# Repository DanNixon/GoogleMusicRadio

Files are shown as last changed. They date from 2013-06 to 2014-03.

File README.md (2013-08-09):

GoogleMusicRadio
================
Internet radio which streams music form a Google Play library using a Raspberry Pi and Arduino.

Overview
--------
Allows browsing and playing tracks from a Google Play music library on a hardware internet radio, browsing library is done through a Artist>Album>Track menu structure (or a Playlist>Track structure in the case of playlists).

The radio is intended to be used with [Last.fm](http://last.fm) to report the currently playing track, scrobble listened tracks and to love tracks at the request of the user.

A basic user interface of 6 buttons, two rotary encoders with push in switches and a 4 row, 20 column LCD is used, although it is possible to use various sizes of LCD based on specific user requirements enclosure designs.

Note that this radio is designed to work with a personal library only, personally I don't use the All Access service so have no need to support it, but feel free to add this functionality, the Google Music API does support All Access radio.

Requirements
------------
Libraries required for Arduino and Raspberry Pi are listed in the respective folders.

Build Instructions
------------------
A complete guide to building a radio is available [here](http://www.instructables.com/id/Google-Play-Music-Internet-Radio-Raspberry-Pi-and/) on Instructbles.

A demo of the final project is available [here](http://www.youtube.com/watch?v=tgPbvo-8iRc).

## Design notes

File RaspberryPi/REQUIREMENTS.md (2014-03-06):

Requirements
============

The following libraries need to be installed on the Pi:
-	[Google Music API](https://github.com/simon-weber/Unofficial-Google-Music-API) (currently requires ```develop``` branch)
-	[GStreamer](http://gstreamer.freedesktop.org/) (core and Python bindings)
-	[pyLast](http://code.google.com/p/pylast/)
-	[pySerial](http://pyserial.sourceforge.net/)

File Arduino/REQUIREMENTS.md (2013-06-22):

Requirements
============

The following Arduino libraries are needed:
-	LiquidCrystal (in default libraries)
-	[Encoder](http://www.pjrc.com/teensy/td_libs_Encoder.html)
-	[CmdMessenger](http://playground.arduino.cc/Code/CmdMessenger)
-	[Streaming](http://arduiniana.org/libraries/streaming/) (needed by CmdMessenger)

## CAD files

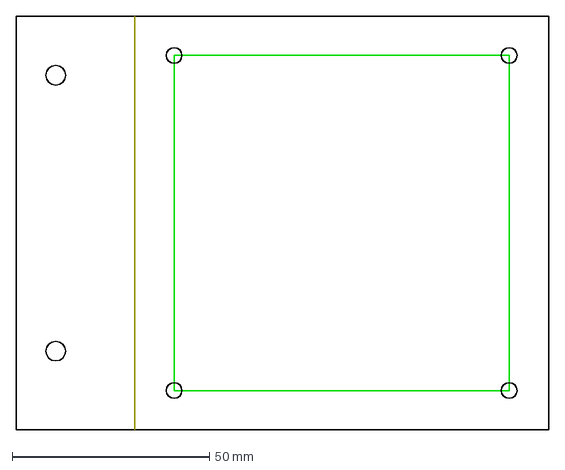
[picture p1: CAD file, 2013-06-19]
LibreCAD/MainBoardMount.dxf
135.0 x 105.0 mm

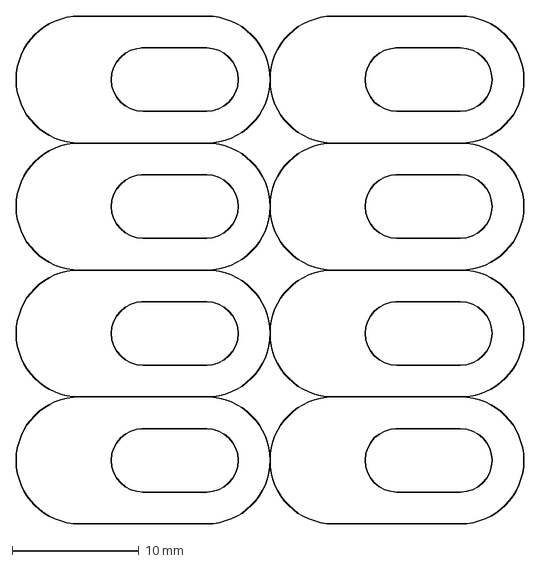
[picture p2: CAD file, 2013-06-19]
LibreCAD/LCD_Retainer.dxf
40.0 x 40.0 mm

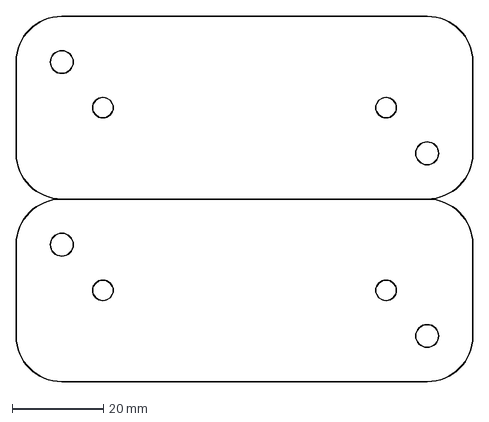
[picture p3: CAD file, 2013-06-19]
LibreCAD/AmplifierMounts.dxf
100.0 x 80.0 mm

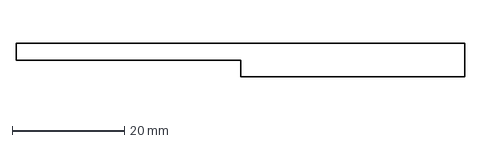
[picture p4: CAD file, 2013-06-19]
LibreCAD/LCD_Spacer.dxf
80.0 x 6.00 mm

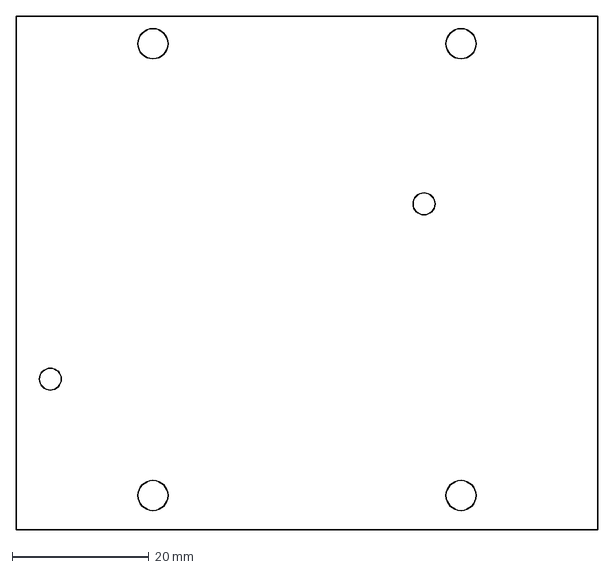
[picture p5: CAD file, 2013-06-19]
LibreCAD/RaspPiMount_GPR.dxf
85.0 x 75.0 mm

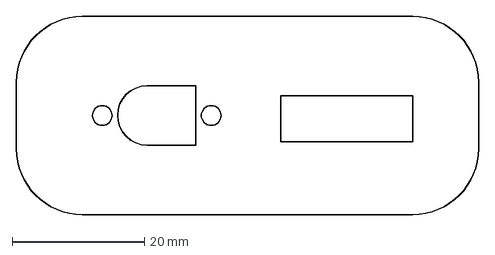
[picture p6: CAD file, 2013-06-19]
LibreCAD/GPR_RearPower.dxf
70.0 x 30.0 mm

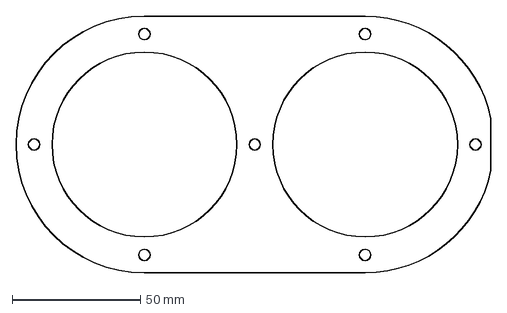
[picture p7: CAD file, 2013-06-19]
LibreCAD/DualSpeakerMount.dxf
185.0 x 100.0 mm

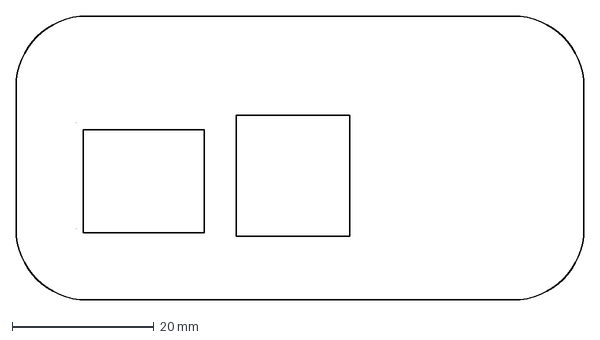
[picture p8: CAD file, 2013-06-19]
LibreCAD/RearRaspPiCover.dxf
80.0 x 40.0 mm

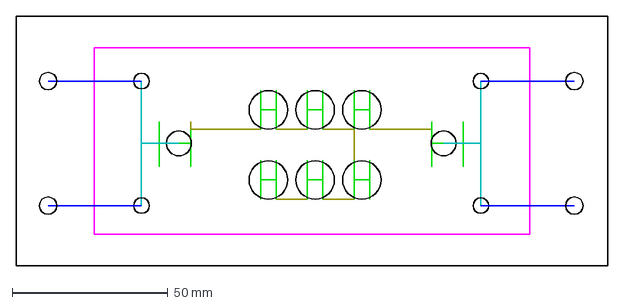
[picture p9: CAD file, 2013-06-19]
LibreCAD/GPR_FrontPanel_A.dxf
190.0 x 80.0 mm

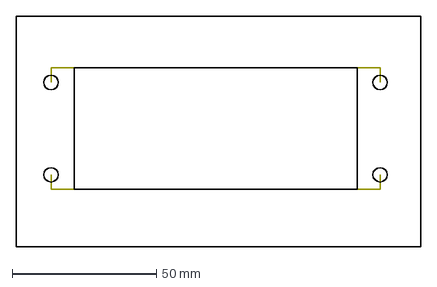
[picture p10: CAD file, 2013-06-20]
LibreCAD/LCD_Screw_Template.dxf
140.0 x 80.0 mm

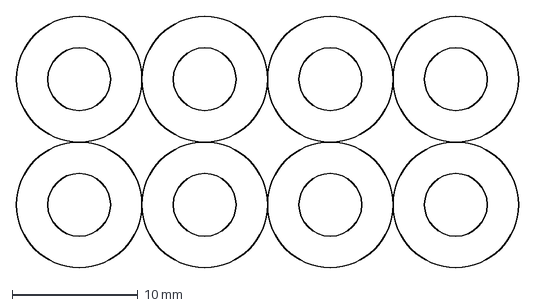
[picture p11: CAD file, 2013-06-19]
LibreCAD/Washers.dxf
40.0 x 20.0 mm

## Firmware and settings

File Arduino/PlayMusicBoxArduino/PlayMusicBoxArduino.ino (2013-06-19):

/*
  Google Pay Music Radio Arduino script
  Dan Nixon 2013
  dan-nixon.com
  
  11/04/2013
*/

#include <Encoder.h>
#include <LiquidCrystal.h>
#include <CmdMessenger.h>
#include <Streaming.h>

#define PORT_SPEED 115200

char field_separator = '%';
char command_separator = '~';

const int ADC_TH = 100;
const int DB_TIME = 20;

const int LCD_ROWS = 4;
const int LCD_COLS = 20;

//LCD PINS
#define LCD_D4 11
#define LCD_D5 10
#define LCD_D6 9
#define LCD_D7 8
#define LCD_RS 13
#define LCD_EN 12

//ENCODERS
#define VOL_ENC_A 3
#define VOL_ENC_B 5
#define CUR_ENC_A 2
#define CUR_ENC_B 4
long volEncPos = -999;
long curEncPos = -999;
static const int VOL_ENCODER_DELTA = 1;
static const int CUR_ENCODER_DELTA = 1;

//ENCODER BUTTONS
#define SELECT_PIN 6
boolean selLast = false;
#define MUTE_PIN 7
boolean muteLast = false;

//ADC BUTTONS
#define STOP_ADC 0
boolean stopLast = false;
#define PLAY_ADC 1
boolean playLast = false;
#define NEXT_ADC 2
boolean nextLast = false;
#define LOVE_ADC 4
boolean loveLast = false;
#define DISP_ADC 3
boolean dispLast = false;
#define BACK_ADC 5
boolean backLast = false;

Encoder volumeEnc(VOL_ENC_A, VOL_ENC_B);
Encoder cursorEnc(CUR_ENC_A, CUR_ENC_B);
CmdMessenger msgr = CmdMessenger(Serial, field_separator, command_separator);
LiquidCrystal lcd(LCD_RS, LCD_EN, LCD_D4, LCD_D5, LCD_D6, LCD_D7);

//COMMAND LIST
enum
{
  kCOMM_ERROR    = 000,
  kACK           = 001,
  kARDUINO_READY = 002,
  kERR           = 003,
  kNEXT          = 012, //10
  kSTOP          = 013,
  kPLAY          = 014,
  kBACK          = 015,
  kINCVOL        = 016,
  kDECVOL        = 017,
  kUP            = 020,
  kDOWN          = 021,
  kSEL           = 022,
  kDISP          = 023,
  kLOVE          = 024, //20
  kMUTE          = 025,
  kSEND_CMDS_END,
};

messengerCallbackFunction messengerCallbacks[] = 
{
  lcdPrint,
  lcdVolume,
  lcdClear,
  NULL
};

//CALLBACKS
void lcdPrint() {
  msgr.sendCmd(kACK, "LCD_P");
  int rowNo = msgr.readInt();
  char row[LCD_COLS + 1] = {};
  msgr.copyString(row, (LCD_COLS + 1));
  lcd.setCursor(0, rowNo);
  lcd.print(row);
}

void lcdClear() {
  msgr.sendCmd(kACK, "LCD_C");
  lcd.clear();
}

void lcdVolume() {
  msgr.sendCmd(kACK, "VOL_P");
  int volume = msgr.readInt();
  float barRange = LCD_COLS - 2;
  float barWeight = 64.0 / barRange;
  int barQuant = (int) (volume / barWeight);
  lcd.clear();
  lcd.setCursor(0,0);
  lcd.print("Volume: ");
  lcd.setCursor(8, 0);
  lcd.print(volume);
  lcd.setCursor(0, 1);
  lcd.print("[");
  lcd.setCursor((LCD_COLS - 1), 1);
  lcd.print("]");
  lcd.setCursor(1, 1);
  for(int i = 0; i < barQuant; i++) {
    lcd.write(255);
  }
}

//DEFAULT CALLBACKS
void arduino_ready() {
  msgr.sendCmd(kACK,"READY");
}

void unknownCmd() {
  msgr.sendCmd(kERR,"U_CMD");
}

//SETUP

void attach_callbacks(messengerCallbackFunction* callbacks) {
  int i = 0;
  int offset = kSEND_CMDS_END;
  while(callbacks[i]) {
    msgr.attach(offset+i, callbacks[i]);
    i++;
  }
}

void setup() {
  Serial.begin(PORT_SPEED);
  msgr.print_LF_CR();
  msgr.attach(kARDUINO_READY, arduino_ready);
  msgr.attach(unknownCmd);
  attach_callbacks(messengerCallbacks);
  lcd.begin(LCD_COLS, LCD_ROWS);
  //PIN CONFS
  pinMode(SELECT_PIN, INPUT);
  digitalWrite(SELECT_PIN, HIGH);
  pinMode(MUTE_PIN, INPUT);
  digitalWrite(MUTE_PIN, HIGH);
  long volEncPos = volumeEnc.read();
  long curEncPos = cursorEnc.read();
  arduino_ready();
  lcd.print("Waiting for Pi...");
}

//MAIN LOOP
void checkButtons() {
  if(analogRead(PLAY_ADC) <= ADC_TH) {
    if(playLast == false) {
      msgr.sendCmd(kPLAY, "PLAY");
      delay(DB_TIME);
      playLast = true;
    }
  } else {
    if(playLast == true) {
      playLast = false;
    }
  }
  
  if(analogRead(STOP_ADC) <= ADC_TH) {
    if(stopLast == false) {
      msgr.sendCmd(kSTOP, "STOP");
      delay(DB_TIME);
      stopLast = true;
    }
  } else {
    if(stopLast == true) {
      stopLast = false;
    }
  }
  
  if(analogRead(NEXT_ADC) <= ADC_TH) {
    if(nextLast == false) {
      msgr.sendCmd(kNEXT, "NEXT");
      delay(DB_TIME);
      nextLast = true;
    }
  } else {
    if(nextLast == true) {
      nextLast = false;
    }
  }
  
  if(analogRead(BACK_ADC) <= ADC_TH) {
    if(backLast == false) {
      msgr.sendCmd(kBACK, "BACK");
      delay(DB_TIME);
      backLast = true;
    }
  } else {
    if(backLast == true) {
      backLast = false;
    }
  }
  
  if(analogRead(DISP_ADC) <= ADC_TH) {
    if(dispLast == false) {
      msgr.sendCmd(kDISP, "DISP");
      delay(DB_TIME);
      dispLast = true;
    }
  } else {
    if(dispLast == true) {
      dispLast = false;
    }
  }
  
  if(analogRead(LOVE_ADC) <= ADC_TH) {
    if(loveLast == false) {
      msgr.sendCmd(kLOVE, "LOVE");
      delay(DB_TIME);
      loveLast = true;
    }
  } else {
    if(loveLast == true) {
      loveLast = false;
    }
  }
  if(digitalRead(SELECT_PIN) == LOW) {
    if(selLast == false) {
      msgr.sendCmd(kSEL, "SEL");
      delay(DB_TIME);
      selLast = true;
    }
  } else {
    if(selLast == true) {
      selLast = false;
    }
  }
  if(digitalRead(MUTE_PIN) == LOW) {
    if(muteLast == false) {
      msgr.sendCmd(kMUTE, "MUTE");
      delay(DB_TIME);
      selLast = true;
    }
  } else {
    if(muteLast == true) {
      muteLast = false;
    }
  }
}

void checkEncoders() {
  long newVolEncPos = volumeEnc.read();
  if(newVolEncPos > (volEncPos + VOL_ENCODER_DELTA)) {
    msgr.sendCmd(kDECVOL, "DECVOL");
    volEncPos += VOL_ENCODER_DELTA;
  }
  else if(newVolEncPos < (volEncPos - VOL_ENCODER_DELTA)) {
    msgr.sendCmd(kINCVOL, "INCVOL");
    volEncPos -= VOL_ENCODER_DELTA;
  }
  
  long newCurEncPos = cursorEnc.read();
  if(newCurEncPos > (curEncPos + CUR_ENCODER_DELTA)) {
    msgr.sendCmd(kUP, "UP");
    curEncPos += CUR_ENCODER_DELTA;
  }
  else if(newCurEncPos < (curEncPos - CUR_ENCODER_DELTA)) {
    msgr.sendCmd(kDOWN, "DOWN");
    curEncPos -= CUR_ENCODER_DELTA;
  }
}

void loop() 
{
  msgr.feedinSerialData();
  checkButtons();
  checkEncoders();
}

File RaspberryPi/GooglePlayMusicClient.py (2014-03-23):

#!/usr/bin/python

## Google Play Music client script for Rasp. Pi radio
## Copyright: Dan Nixon 2012-13
## dan-nixon.com
## Version: 0.4
## Date: 04/03/2014

import thread, time, random, string
from gmusicapi import Mobileclient
import RPi.GPIO as gpio
import smbus
import serial
import gobject, glib
import gst

#__MusicClient__ = None
#__MediaPlayer__ = None
#__VolumeMan__ = None
#__LCDMan__ = None
#__LastFm__ = None
#__LCDMenuMan__ = None
__SerialPort__ = None

class switch(object):
	def __init__(self, value):
		self.value = value
		self.fall = False

	def __iter__(self):
		yield self.match
		raise StopIteration
    
	def match(self, *args):
		if self.fall or not args:
			return True
		elif self.value in args:
			self.fall = True
			return True
		else:
			return False

class GPMClient(object):
	all_songs_album_title = "All Songs"
	thumbs_up_playlist_name = "Thumbs Up"

	def __init__(self, email, password, device_id):
		self.__api = Mobileclient()
		self.logged_in = False
		self.__device_id = device_id

		attempts = 0
		while not self.logged_in and attempts < 3:
			self.logged_in = self.__api.login(email, password)
			attempts += 1

		self.all_tracks = dict()
		self.playlists = dict()
		self.library = dict()

	def __del__(self):
		self.__api.logout()

	def update_local_lib(self):
		print "Getting all library tracks"
		songs = self.__api.get_all_songs()
		self.playlists[self.thumbs_up_playlist_name] = list()

		#	Get main library
		print "Processing library tracks"
		song_map = dict()	
		for song in songs:
			if "rating" in song and song["rating"] == "5":
				self.playlists[self.thumbs_up_playlist_name].append(song)

			song_id = song["id"]
			song_artist = song["artist"]
			song_album = song["album"]

			song_map[song_id] = song

			if song_artist == "":
				song_artist = "Unknown Artist"

			if song_album == "":
				song_album = "Unknown Album"

			if not (song_artist in self.library):
				self.library[song_artist] = dict()
				self.library[song_artist][self.all_songs_album_title] = list()

			if not (song_album in self.library[song_artist]):
				self.library[song_artist][song_album] = list()

			self.library[song_artist][song_album].append(song)
			self.library[song_artist][self.all_songs_album_title].append(song)

		# Sort albums by track number
		print "Sorting library tracks"
		for artist in self.library.keys():
			for album in self.library[artist].keys():
				if album == self.all_songs_album_title:
					sorted_album = sorted(self.library[artist][album], key=lambda k: k['title'])
				else:
					sorted_album = sorted(self.library[artist][album], key=lambda k: k['trackNumber'])
				self.library[artist][album] = sorted_album

		#	Get all playlists
		print "Getting user playlists"
		plists = self.__api.get_all_user_playlist_contents()
		for plist in plists:
			plist_name = plist["name"]
			self.playlists[plist_name] = list()
			for track in plist["tracks"]:
				song = song_map[track["trackId"]]
				self.playlists[plist_name].append(song)

	def get_stream_url(self, song):
		return self.__api.get_stream_url(song["id"], self.__device_id)

	def rate_song(self, song, rating):
		try:
			song["rating"] = rating
			song_list = [song]
			self.__api.change_song_metadata(song_list)
			print "Gave a Thumbs Up to {0} by {1} on Google Play.".format(song["title"].encode("utf-8"), song["artist"].encode("utf-8"))
		except:
			print "Error giving a Thumbs Up on Google Play."

class MediaPlayer(object):
	def __init__(self):
		self.__player = None
			
		self.now_playing_song = None
		self.queue = list()
		self.queue_index = -1

		self.random = False
		self.repeat = True

		thread.start_new_thread(self.player_thread, ())
	
	def __del__(self):
		self.now_playing_song = None
		self.__player.set_state(gst.STATE_NULL)
	
	def player_thread(self):
		if self.__player == None:
			print "Creating a new GStreamer player..."
			self.__player = gst.element_factory_make("playbin2", "player")
			self.__player.set_state(gst.STATE_NULL)
			bus = self.__player.get_bus()
			bus.add_signal_watch()
			bus.connect("message", self.handle_song_end)
			glib.MainLoop().run()
		else:
			print "Player already exists!"
	
	def get_state(self):
		return self.__player.get_state()[1]

	def handle_song_end(self, bus, message):
		if message.type == gst.MESSAGE_EOS:
			__LastFm__.scrobble(self.now_playing_song)
			self.stop()
			print "Finished playing last song"
			self.play_next_in_queue()
	
	def clear_queue(self):
		self.queue = list()
		self.queue_index = -1
		__LCDMenuMan__.update_queue()

	def play(self, song):
		print "Song: ", song
		song_url = __MusicClient__.get_stream_url(song)
		print "Got song URL: ", song_url
		try:
			print "Playing song."
			if not __VolumeMan__.is_mute:
				__VolumeMan__.set_amp_power(True)
			self.__player.set_property("uri", song_url)
			self.__player.set_state(gst.STATE_PLAYING)
			self.now_playing_song = song
			time.sleep(0.5)
			__LCDMan__.update()
		except AttributeError:
			print "Player does not yet exist!"
		__LastFm__.update_now_playing(song)

	def toggle_playback(self):
		try:
			player_state = self.__player.get_state()[1]
			if player_state == gst.STATE_PAUSED:
				print "Resuming paused playback"
				if not __VolumeMan__.is_mute:
					__VolumeMan__.set_amp_power(True)
				self.__player.set_state(gst.STATE_PLAYING)
				if __LCDMan__.lcd_base == __LCDMan__.base_playing:
					__LCDMan__.update()
			elif player_state == gst.STATE_PLAYING:
				print "Pausing playback"
				self.__player.set_state(gst.STATE_PAUSED)
				if not __VolumeMan__.is_mute:
					__VolumeMan__.set_amp_power(False)	
				if __LCDMan__.lcd_base == __LCDMan__.base_playing:
					__LCDMan__.update()
			elif player_state == gst.STATE_NULL:
				print "Nothing in player"
				self.play_next_in_queue()
				if __LCDMan__.lcd_base == __LCDMan__.base_playing:
					__LCDMan__.update()
		except AttributeError:
			print "Player does not yet exist!"

	def stop(self):
		try:
			print "Stopping playback"
			self.__player.set_state(gst.STATE_NULL)
			self.now_playing_song = None
		except AttributeError:
			print "Player does not yet exist!"

	def play_next_in_queue(self):
		print "Playing next song in queue"
		if self.random:
			self.queue_index = random.randint(0, (len(self.queue) - 1))
		else:
			self.queue_index = self.queue_index + 1
		if self.queue_index == len(self.queue):
			if self.repeat:
				self.queue_index = 0
			else:
				self.stop()
				__VolumeMan__.set_amp_power(False)
				print "The queue is empty!"
				return
		next_song = self.queue[self.queue_index]
		self.play(next_song)

	def add_to_queue(self, song):
		print "Adding song to queue. Song ID: ", song["id"]
		self.queue.append(song)
		__LCDMenuMan__.update_queue()

	def next(self):
		__LastFm__.scrobble(self.now_playing_song)
		self.stop()
		self.play_next_in_queue()
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

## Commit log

2013-06-19 Added KiCAD files
    [MainBoard.sch]
2013-06-20 Finished speaker mount and added LCD mounting screw template
    [LCD_Screw_Template.dxf]
2013-06-24 Updated script for new API, fixed bugs
    [GooglePlayMusicClient.py]
2013-06-25 Fixed bugs and issue #1
    [GooglePlayMusicClient.py]
2013-06-25 Fixed artist letter selection sorting bug
    [GooglePlayMusicClient.py]
2013-06-27 Fixed issue #2 + bug fixes
    [GooglePlayMusicClient.py]
2013-07-16 Added LCD update delay after play song
    Fixed strange behaviour which causes Arduino to loose connectivity to the LCD when changing song.
    [GooglePlayMusicClient.py]
2013-07-16 LCD big fix
    This actually fixes the LCD bug that the last commit was supposed to.
    [GooglePlayMusicClient.py]
2013-07-17 Bug fixes and general improvement
    Fixes unlikely case which causes Arduino to hang/reset.
    Amplifier power is no longer toggled during song switch.
    [GooglePlayMusicClient.py]
2013-07-18 Fixed several things
    Fixed issue #3, more consistent LCD messages, better organised Settings menu (now using list instead of dict)
    [GooglePlayMusicClient.py]
2013-08-31 Fixed LCD bug
    First call to writeLCD would cause unwanted characters on LCD if shorter than "Waiting for Pi..." message.
    [GooglePlayMusicClient.py]
2014-03-04 Switch to mobile client, new client code, major refactoring
2014-03-05 More refactoring and corrections
    [GooglePlayMusicClient.py]
2014-03-05 Error handling and refactoring
    [GooglePlayMusicClient.py]
2014-03-06 Fixed some small issues Removed playlist track sorting (gives user order)
    [GooglePlayMusicClient.py]
2014-03-23 Fixed CPU usage issue, removes audio issues caused by high CPU load
    [GooglePlayMusicClient.py]
